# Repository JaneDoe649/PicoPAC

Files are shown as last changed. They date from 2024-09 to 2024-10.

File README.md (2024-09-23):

# PicoPAC
**Thanks to Aotta and the other contributors for this wonderful work that brings our old consoles back to life!**

**NOTE** FORK WORK IN PROGRESS (More test are needed):
- Navigating the SD card tree (limited to one sub-level and 5 chars directory names) from the menu successfully tested on the C52;
- Override extram readings at 0xff to request menu refresh;
- For ROMs referenced in MAME, the name of the game is displayed in the menu;
- Resetting after loading the game is tricky but seems to work (at least on my C52).

Flashcart for Videopac / Odyssey 2 based on Wilco2009 Videopac-microSD card project
Based on SD card by Wilco2009: https://github.com/wilco2009/Videopac-micro-SD-Cart , my greetings for his fantastic job!

Since now, tested on  G-7000, G7400, C52, JOPAC and Odyssey 2. Waiting for a friend that has to repair his G7200 for completing the list ;) 

Added support to extROM games too (VP_40, VP_31 and 4INAROW.BIN).

PicoPAC is a multicart DIY yourself based on cheap "PURPLE" Raspberry Pi Pico clone, easy to build and not expensive.
**WARNING!** "purple" Pico has not the same pinout of original Raspberry "green" ones, you MUST use the clone or you may damage your hardware. 
**Several pinouts exist depending on the clone manufacturer. The pinout corresponding to the PCB is as follows :**
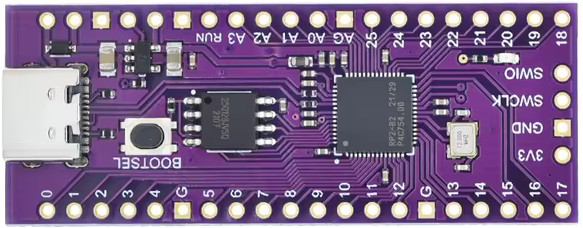
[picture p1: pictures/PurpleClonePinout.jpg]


**NOTE** You should find all the ROM with matching filenames following this site https://rene-g7400.datatex.nl/ 

Please don't forget to upload the here provided "selectgame.bin" file in flash!!!!








Kicad project and gerbers files for the pcb are in the PCB folder, you need only a diode and a push buttons for resetting the cart if needed or want restart. 
Add you pico clone, and flash the firmware ".uf2" in the Pico by connecting it while pressing button on Pico and drop it in the opened windows on PC.
After flashed with firmware, and every time you have to change your ROMS repository, you can simply connect the Pico to PC and drag&drop "BIN" files  into.
But remember that only games already in menu will be seen by the cart.

Even if the diode should protect your console, **DO NOT CONNECT PICO WHILE INSERTED IN A POWERED ON CONSOLE!**

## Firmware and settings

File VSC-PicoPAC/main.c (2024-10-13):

/*
//                       PicoPAC MultiCART by Andrea Ottaviani 2024
//
//  VIDEOPAC  multicart based on Raspberry Pico board -
//
//  More info on https://github.com/aotta/ 
//
//   parts of code are directly from the A8PicoCart project by Robin Edwards 2023
//  
//   Needs to be a release NOT debug build for the cartridge emulation to work
// 
//   Edit myboard.h depending on the type of flash memory on the pico clone//
//
//   v. 1.0 2024-08-05 : Initial version for Pi Pico 
//
*/



#include <stdio.h>
#include <string.h>

#include "pico/stdlib.h"
#include "pico/time.h"
#include "tusb.h"

#include "picopac_cart.h"
#include "fatfs_disk.h"

void picopac_cart_main();

//#define debugging

//--------------------------------------------------------------------+
// USB CDC
//--------------------------------------------------------------------+
void cdc_task(void)
{
  // connected() check for DTR bit
  // Most but not all terminal client set this when making connection
  // if ( tud_cdc_connected() )
  {
    // connected and there are data available
    if ( tud_cdc_available() )
    {
      // read data
      char buf[64];
      uint32_t count = tud_cdc_read(buf, sizeof(buf));
      (void) count;

      // Echo back
      // Note: Skip echo by commenting out write() and write_flush()
      // for throughput test e.g
      //    $ dd if=/dev/zero of=/dev/ttyACM0 count=10000
      tud_cdc_write(buf, count);
      tud_cdc_write_flush();
    }
  }
}

// Invoked when cdc when line state changed e.g connected/disconnected
void tud_cdc_line_state_cb(uint8_t itf, bool dtr, bool rts)
{
  (void) itf;
  (void) rts;

  // TODO set some indicator
  if ( dtr )
  {
    // Terminal connected
  }else
  {
    // Terminal disconnected
  }
}

// Invoked when CDC interface received data from host
void tud_cdc_rx_cb(uint8_t itf)
{
  (void) itf;
}


int main(void)
{
   //tusb_init();
   //stdio_init_all();   // for serial output, via printf()
   
    //tud_init(BOARD_TUD_RHPORT);
    gpio_init_mask(FLAG_MASK);
    gpio_set_dir_in_masked(FLAG_MASK);
    gpio_init(PICO_DEFAULT_LED_PIN);
    gpio_set_dir(PICO_DEFAULT_LED_PIN,true);
    gpio_put(PICO_DEFAULT_LED_PIN,true);
   
   /*stdio_init_all();   // for serial output, via printf()
   while (1) {
      uint32_t pins=gpio_get_all();
			if (pins & RESTART) {
				printf("RESTART");
			} else {
				printf("NO RESTART");
			} 			
   }*/
    //while(1) {          
      
    while (to_ms_since_boot(get_absolute_time()) < 100) 
    {
       #ifndef debugging
       if (gpio_get(PSEN_PIN)==1)
       #endif
          picopac_cart_main();
    }

     
       // init device stack on configured roothub port
       // we are presumably powered from USB
       // enter USB mass storage mode
     //  tud_init(BOARD_TUD_RHPORT);
     //  stdio_init_all();   // for serial output, via printf()
       // printf("Start Storage mode\n");
      stdio_init_all();   // for serial output, via printf()
      #ifdef debugging
      printf("Start up\n");  
      #endif

      // init device stack on configured roothub port
      tud_init(BOARD_TUD_RHPORT);


       while (1) {
          tud_task(); // tinyusb device task
         
          cdc_task();
       }
    
    //}
   return 0;
}

//--------------------------------------------------------------------+
// Device callbacks
//--------------------------------------------------------------------+

// Invoked when device is mounted
void tud_mount_cb(void)
{
  printf("Device mounted\n"); 
  if (!mount_fatfs_disk())
    create_fatfs_disk();
}

// Invoked when device is unmounted
void tud_umount_cb(void)
{
  printf("Device unmounted\n");  
}

// Invoked when usb bus is suspended
// remote_wakeup_en : if host allow us  to perform remote wakeup
// Within 7ms, device must draw an average of current less than 2.5 mA from bus
void tud_suspend_cb(bool remote_wakeup_en)
{
  (void) remote_wakeup_en;
//  blink_interval_ms = BLINK_SUSPENDED;
}

// Invoked when usb bus is resumed
void tud_resume_cb(void)
{
//  blink_interval_ms = BLINK_MOUNTED;
}

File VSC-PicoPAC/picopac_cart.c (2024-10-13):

/*
//                       PicoPAC MultiCART by Andrea Ottaviani 2024
//
//  VIDEOPAC  multicart based on Raspberry Pico board -
//
//  More info on https://github.com/aotta/ 
//
//   parts of code are directly from the A8PicoCart project by Robin Edwards 2023
//  
//   Needs to be a release NOT debug build for the cartridge emulation to work
// 
//   Edit myboard.h depending on the type of flash memory on the pico clone//
//
//   v. 1.0 2024-08-05 : Initial version for Pi Pico 
//
*/

//#define debugging
//#define optimize
#define maxfiles 200

#include <stdio.h>
#include <stdlib.h>
#include <string.h>
#include "pico/multicore.h"
#include "hardware/gpio.h"
#include "pico/platform.h"
#include "pico/stdlib.h"
#include "hardware/vreg.h"
#include "pico/divider.h"
#include "hardware/flash.h"
#include "hardware/sync.h"


#include "selectgame.h"

#include "tusb.h"
#include "ff.h"
#include "fatfs_disk.h"
#include <sys/types.h>
#include "hardware/clocks.h"

#include "translate.c"
#include "picopac_cart.h"

#ifdef optimize
#include "pico/time.h"
uint32_t msSinceBoot1;
uint32_t msSinceBoot2;
#endif


 void picopac_cart_main();
 void updaterom(unsigned char *m, int memblock);
 #ifdef debugging
 void debugFS(unsigned char *array);
 #endif

// We're going to erase and reprogram a region 256k from the start of flash.
// Once done, we can access this at XIP_BASE + 256k.


//#define BINLENGTH  1024*128+1
unsigned char __attribute__((aligned(4))) rom_table[2][8][4096];
volatile int rom_buffer = 0;
volatile int next_rom_buffer = 1;
unsigned char extROM[1024];
unsigned char RAM[1024];

char path[5];
char errorBuf[40];
int romsize;
volatile u_int8_t bank_type=1;
volatile u_int8_t new_bank_type=1;
volatile char gamechoosen=0;
//volatile char newgame=0;
volatile char resetnow=0;
volatile char menu_loaded=0;
char extram[0xff];


////////////////////////////////////////////////////////////////////////////////////
//                     Error(N)
////////////////////////////////////////////////////////////////////////////////////
void error(int numblink){
 	multicore_lockout_start_blocking();	
    sleep_ms(1000);
	gpio_init(PICO_DEFAULT_LED_PIN);
	gpio_set_dir(PICO_DEFAULT_LED_PIN,GPIO_OUT);
  while(1){

    for(int i=0;i<numblink;i++) {
      gpio_put(PICO_DEFAULT_LED_PIN,true);
      sleep_ms(600);
      gpio_put(PICO_DEFAULT_LED_PIN,false);
      sleep_ms(500);
    }
  sleep_ms(2000);
  }
}

/*
 Theory of Operation
 -------------------
 //
 //
 //
*/
#pragma GCC push_options
#pragma GCC optimize ("O3")

void __not_in_flash_func(core1_main()) {
    uint32_t addr;
    char dataWrite=0;
    uint32_t pins;
    u_int8_t bank=0;
	u_int8_t romlatch=0;

	multicore_lockout_victim_init();	
   
    //gpio_set_dir_in_masked(ALWAYS_IN_MASK);

	while(1) {
	//newgame=0;
	gamechoosen=0;
	resetnow=0;

		// Initial conditions
		//SET_DATA_MODE_IN;
		#ifdef optimize
		uint64_t bt = to_us_since_boot(get_absolute_time());
		printf("Boot time : %" PRIu64 " - Ready to play\n", bt);
		#endif
		while(1) {
				pins=gpio_get_all();
				addr = (pins & 0b0111111111111);  
				bank=3-((gpio_get(P10_PIN)+(gpio_get(P11_PIN)*2)));
				if (gpio_get(PSEN_PIN)==0) {
					SET_DATA_MODE_OUT;
						gpio_put_masked(DATA_PIN_MASK,(rom_table[rom_buffer][bank][addr])<<D0_PIN);
						if ((resetnow == 1) && (rom_table[rom_buffer][bank][addr] == 0x00) && (rom_table[rom_buffer][bank][addr-1] == 0x04)) { //JMP 00h on bus
							//newgame=1;
							while (gpio_get(PSEN_PIN)==0) { //Wait end of cycle
							}
							SET_DATA_MODE_IN;
							break;
						}
						if (restart(pins))
							break; 
				}
				if((gpio_get(CS_PIN)==0) && (gpio_get(NOTCS_PIN) == 1) && (gpio_get(WR_PIN)==0)) {
					extram[addr & 0xff]=((pins & DATA_PIN_MASK)>>D0_PIN);	
					if (extram[0xff]==0xaa) {
						gamechoosen=extram[0xfe];
					} 
				}		
			SET_DATA_MODE_IN;
			}
		rom_buffer = next_rom_buffer;
		//SET_DATA_MODE_IN;
		
		switch (new_bank_type) {
		case 0:  // standard 2k / 4k
			while(1) {	
				pins=gpio_get_all();
				addr = (pins & 0b0111111111111);  
				if (gpio_get(P10_PIN)) {
					bank=0;
				} else {
					bank=1;
				}
				if (gpio_get(PSEN_PIN)==0) {
					SET_DATA_MODE_OUT;
					gpio_put_masked(DATA_PIN_MASK,(rom_table[rom_buffer][bank][addr])<<D0_PIN);
				}
				if (restart(pins))
					break;
			SET_DATA_MODE_IN;
			}
			break;
		case 1:  // standard 8k
			while(1) {	
				pins=gpio_get_all();
				addr = (pins & 0b0111111111111);  
				bank=3-((gpio_get(P10_PIN)+(gpio_get(P11_PIN)*2)));
				
				if (gpio_get(PSEN_PIN)==0) {
					SET_DATA_MODE_OUT;
					gpio_put_masked(DATA_PIN_MASK,(rom_table[rom_buffer][bank][addr])<<D0_PIN); 
				}
				if (restart(pins))
						break;
				SET_DATA_MODE_IN;
			}
			break;
		case 2:   // XROM
			while(1) {	
				pins=gpio_get_all();
				addr = (pins & 0b0111111111111); // for all cart but xrom
				if ((gpio_get(P11_PIN)==1 && gpio_get(NOTCS_PIN)==1)) {
						SET_DATA_MODE_OUT;
						gpio_put_masked(DATA_PIN_MASK,(extROM[addr&0x3ff])<<D0_PIN);
				} else {
					if (gpio_get(PSEN_PIN)==0) {
						SET_DATA_MODE_OUT;
						gpio_put_masked(DATA_PIN_MASK,(rom_table[rom_buffer][0][addr])<<D0_PIN);	
					}
				}
				if (restart(pins))
					break; 	
			SET_DATA_MODE_IN;
			}
			break;
		case 3:   // 12k/16k
			while(1) {	
				pins=gpio_get_all();
				addr = (pins & 0b0111111111111); // for all cart but xrom
				if((gpio_get(CS_PIN)==0) && (gpio_get(WR_PIN)==0)) {
					if ((addr & 0xff)>=0x80) {
						romlatch=((~(pins & DATA_PIN_MASK)>>D0_PIN)&7);
					}	
				} else {
				if (gpio_get(P10_PIN)==0) {
					bank=romlatch;
				} else {
					bank=0;
				}
					if (gpio_get(PSEN_PIN)==0) {
						SET_DATA_MODE_OUT;
						gpio_put_masked(DATA_PIN_MASK,(rom_table[rom_buffer][bank][addr])<<D0_PIN);
					}
				}
				if (restart(pins))
					break; 
				SET_DATA_MODE_IN;
			//}
			}
			break;
		}
	}
}

bool  __not_in_flash_func(restart)(uint32_t pins) {
	unsigned char restart_sequence[] = {0x00, 0x00, 0x00, 0x00, // synchronize cpu 
										0x14, 0xF1, // call init
										0xc7, 0x53, 0xf8, 0xd7, // reset stack pointer
										0x04, 0x00}; // jmp 0x00
	int p = 0;
	if (pins & RESTART) {
		menu_loaded = 0; // ask menu loading
		while (!menu_loaded) {
				if (gpio_get(PSEN_PIN)==0) {
				SET_DATA_MODE_OUT;
				gpio_put_masked(DATA_PIN_MASK,(0x00)<<D0_PIN); // wait until menu is loaded with NOP
				while (gpio_get(PSEN_PIN)==0) {} //Wait end of cycle
			}
			SET_DATA_MODE_IN;
		}
		while (p < sizeof(restart_sequence)) {
			if (gpio_get(PSEN_PIN)==0) {
				SET_DATA_MODE_OUT;
				gpio_put_masked(DATA_PIN_MASK,(restart_sequence[p++])<<D0_PIN); // menu is loaded, let's JMP 0x00
				while (gpio_get(PSEN_PIN)==0) {} //Wait end of cycle
			}
			SET_DATA_MODE_IN;
		}
		return true;
	} else {
		return false;
	}
}

#pragma GCC pop_options
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

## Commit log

2024-09-05 Pico pi clone compatible pinout
2024-09-22 Navigating the SD card tree (limited to one sub-level) from the menu successfully tested on the C52; Add EXTRAM readings; For ROMs referenced in MAME, the name of the game is displayed in the menu; T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
    [main.c, picopac_cart.c, picopac_cart.h]
2024-09-23 Reset after game loading fixed (on my C52)
    [picopac_cart.c]
2024-09-23 extram usage corrected, warning needs more test
    [picopac_cart.c, picopac_cart.h]
2024-09-30 correct missing 0xcc command when extram reading
    [picopac_cart.c]
2024-10-06 Reset after game loading fixed
    [main.c, picopac_cart.c]
2024-10-13 faulty attempt to fix in game reset
    [PicoPAC.kicad_sch]
